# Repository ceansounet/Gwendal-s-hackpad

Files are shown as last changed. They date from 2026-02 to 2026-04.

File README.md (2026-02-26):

# Gwendal-s-hackpad
My personnal Hackpad

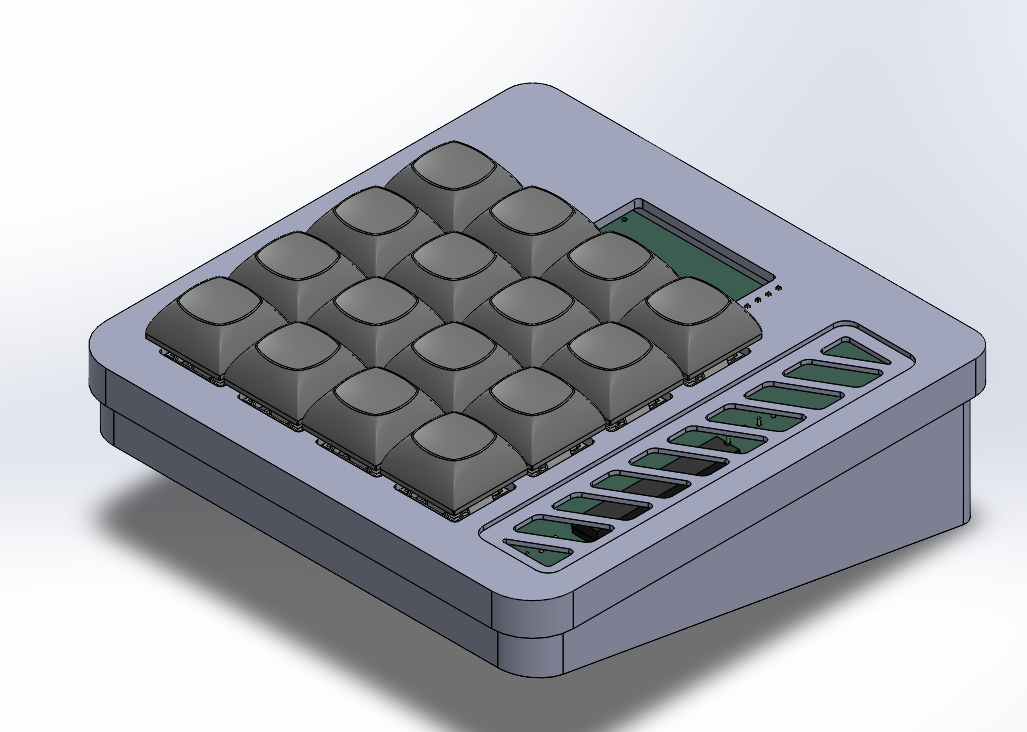
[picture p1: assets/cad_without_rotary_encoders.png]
cad


## PCB
here is the schematic of my pcb :

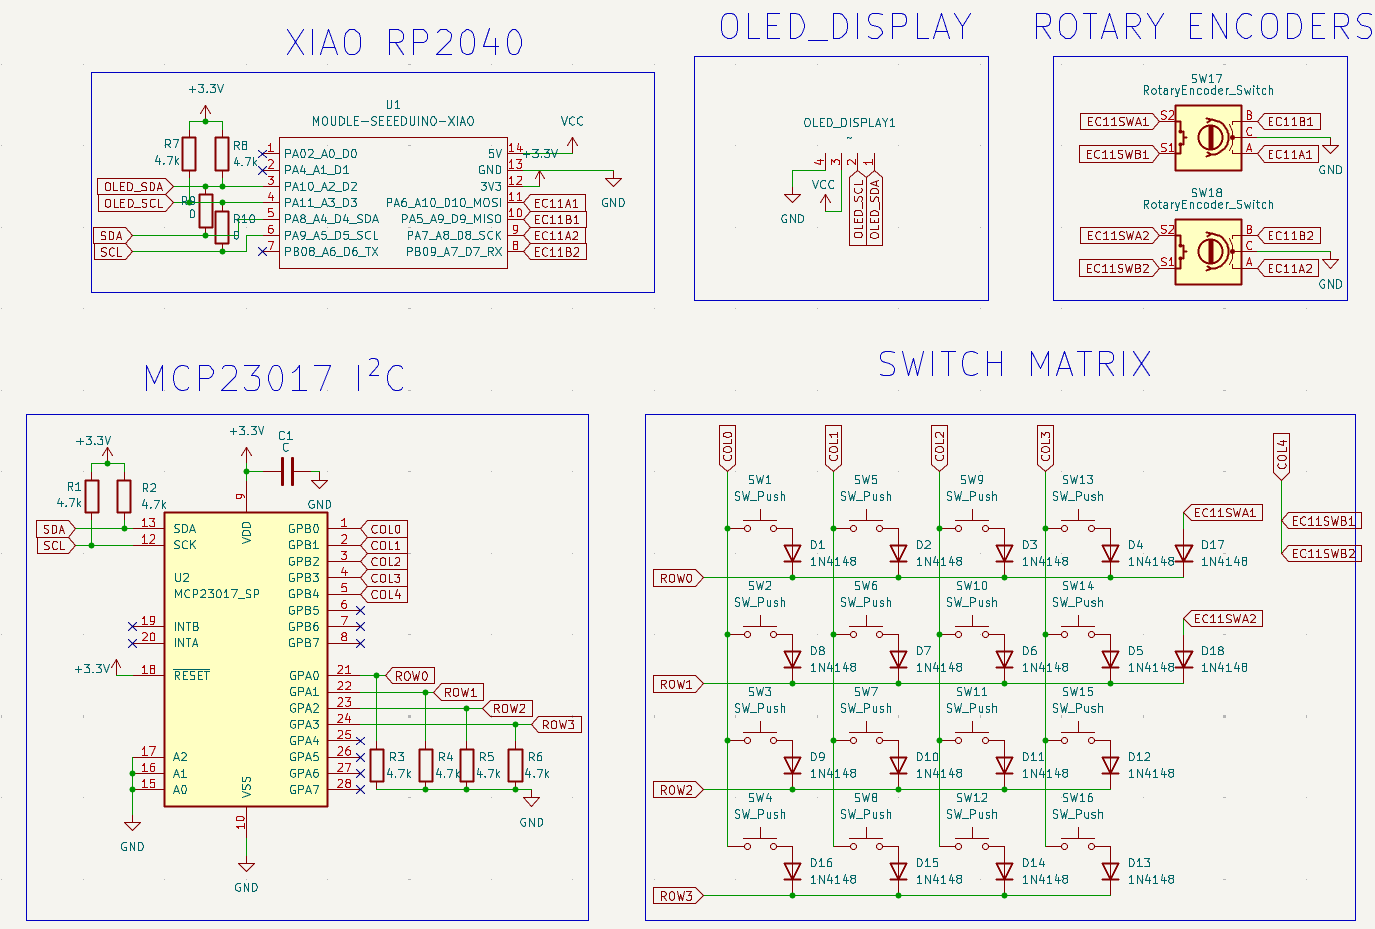
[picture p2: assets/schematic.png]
Schematic


and here is the resulting layout, it needs to be pretty compact to fit in the 100mm*100mm requirements

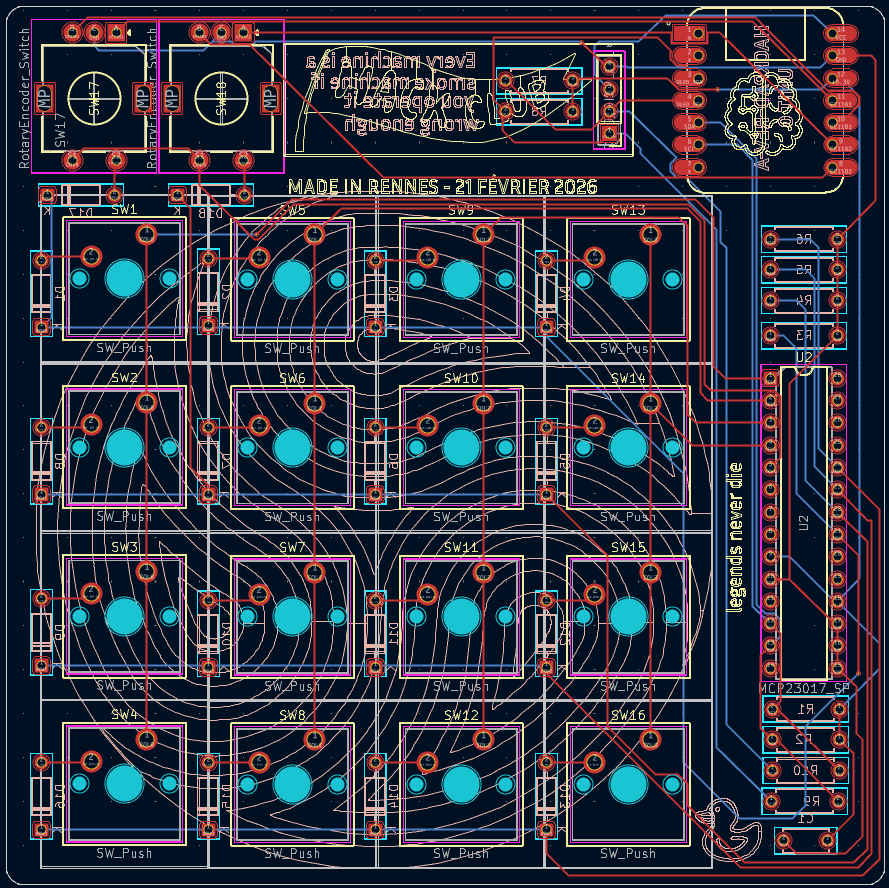
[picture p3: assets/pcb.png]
pcb


The silkscreen was made on figma and imported as an SVG. (sources are [here](pcb/assets))

## BONUS
Since I had extra space and the kit comes with them, I figured I could include the rotary encoders inside a bonus version of my hackpad, while the main version keeps only 16 inputs to fit within the limit

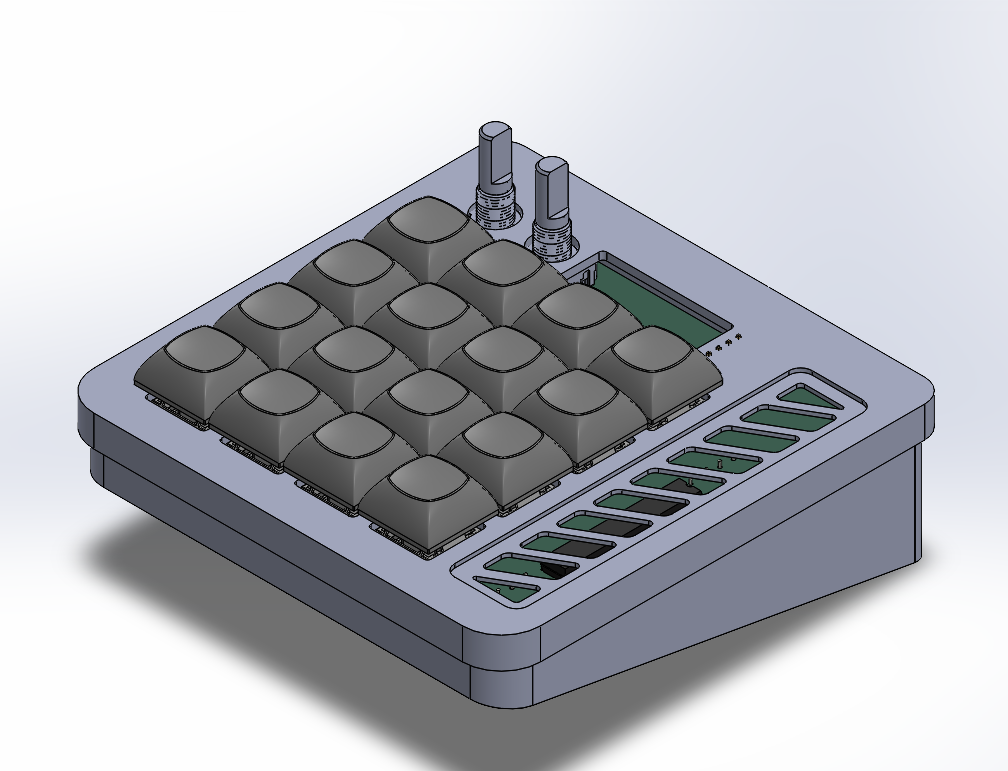
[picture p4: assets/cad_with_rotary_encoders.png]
cad bonus


## BOM:
Here should be everything you need to make this hackpad

in the kit :
- 16x Cherry MX Switches
- 16x DSA Keycaps
- 2x M3x5x4 Heatset inserts
- 2X M3x12mm SHCS Bolts
- 16x 1N4148 DO-35 Diodes
- 1x 0.91" 128x32 OLED Display
- 1x XIAO RP2040
- 1x Case (3 printed parts)

to source yourself :
- 1x MCP23017 (I²C IO expander)
- 1x 100nF Capacitor (decoupling the MCP power)
- 8x 4.7k ohm resistors (pull up/pull down resistors for the matrix and the I²C circuit)

Optional :
- 2x EC11 Rotary Encoder
- 2x 1N4148 DO-35 Diodes
- 1x 8cm² cork sheet (for the bottom of the case)

## EXTRA STUFF :
I designed this project in 4 days of vacation, learnt to use kicad and pcb design in general
If firmware doesn't support 2 different I²C circuits, I added 0 ohm resistors (R9 and R10), that can be soldered shut to make a single I²C circuit, currently it uses 2 by default for speed and stability.
I designed the case to be 3d printable without supports (exept the cutout bit on the top cover, purely for aesthetic purposes, feel free to fill it in to avoid supports entirely).
I made some firmware that should support the matrix, but does not support the encoders nor the OLED screen yet, I am waiting until I have actually made the board to test it.

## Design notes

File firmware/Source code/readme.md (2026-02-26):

# gwendals_hackpad

gwendals_hackpad

*A short description of the keyboard/project*

* Keyboard Maintainer: [gwendal](https://github.com/ceansounet)
* Hardware Supported: RP2040
* Hardware Availability: IDK

Make example for this keyboard (after setting up your build environment):

    make gwendals_hackpad:default

Flashing example for this keyboard:

    make gwendals_hackpad:default:flash

See the [build environment setup](https://docs.qmk.fm/#/getting_started_build_tools) and the [make instructions](https://docs.qmk.fm/#/getting_started_make_guide) for more information. Brand new to QMK? Start with our [Complete Newbs Guide](https://docs.qmk.fm/#/newbs).

## Bootloader

Enter the bootloader in 3 ways:

* **Bootmagic reset**: Hold down the key at (0,0) in the matrix (usually the top left key or Escape) and plug in the keyboard
* **Physical reset button**: Briefly press the button on the back of the PCB - some may have pads you must short instead
* **Keycode in layout**: Press the key mapped to `QK_BOOT` if it is available

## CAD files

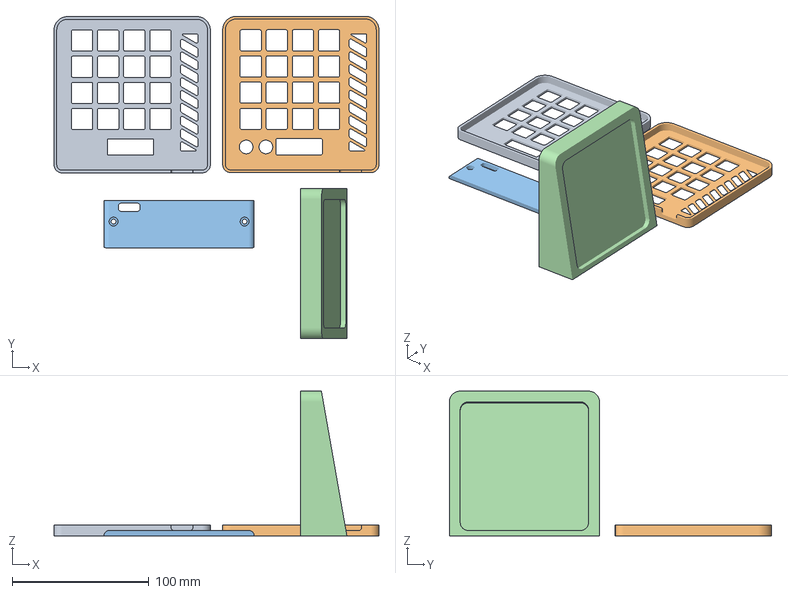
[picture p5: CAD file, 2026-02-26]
cad/3d print file.3mf
238.0 x 236.1 x 106.0 mm
Top_Cover_without_rotary_encoders.STEP
Top_Cover_with_rotary_encoders.STEP
Backplate.STEP
Bottom_part.STEP

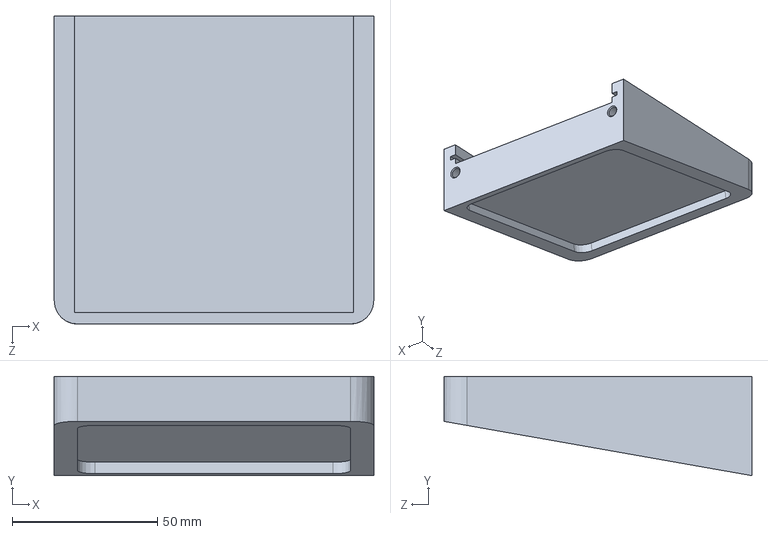
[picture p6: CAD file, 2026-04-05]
cad/Source cad/Bottom_part.SLDPRT
110.0 x 34.2 x 106.0 mm

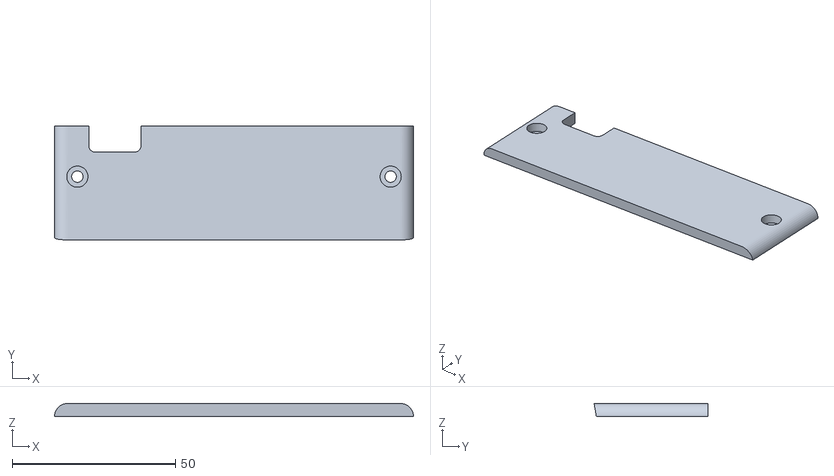
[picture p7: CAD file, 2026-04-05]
production/Backplate.stl
110.0 x 34.9 x 4.00

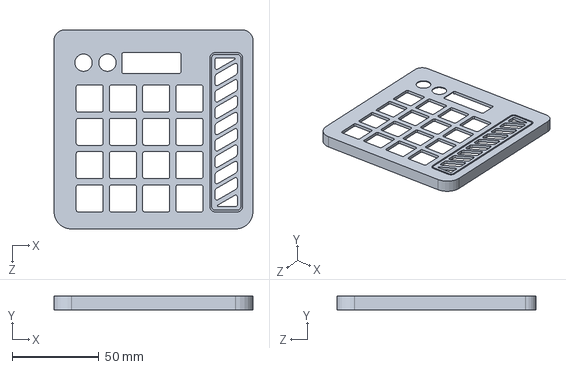
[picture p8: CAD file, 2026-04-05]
cad/Source cad/Top_Cover_with_rotary_encoders.SLDPRT
114.5 x 8.00 x 114.5 mm

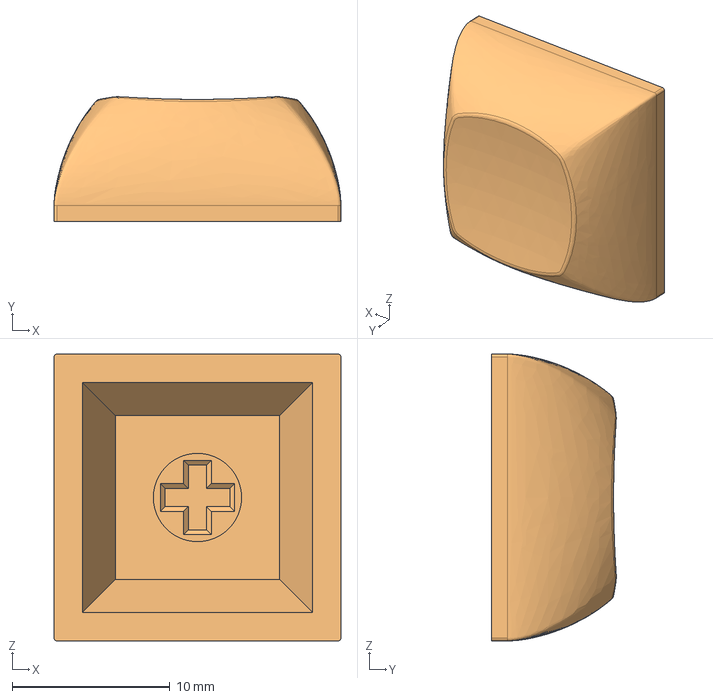
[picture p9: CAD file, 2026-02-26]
cad/Source cad/DSA 1u.step
18.2 x 7.91 x 18.2 mm

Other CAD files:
production/Bottom_part.stl
cad/Source cad/Backplate.SLDPRT
production/Top_Cover.STEP
cad/Source cad/Top_Cover_without_rotary_encoders.SLDPRT
production/Top_cover_BONUS_(with_rotary_encoders).stl

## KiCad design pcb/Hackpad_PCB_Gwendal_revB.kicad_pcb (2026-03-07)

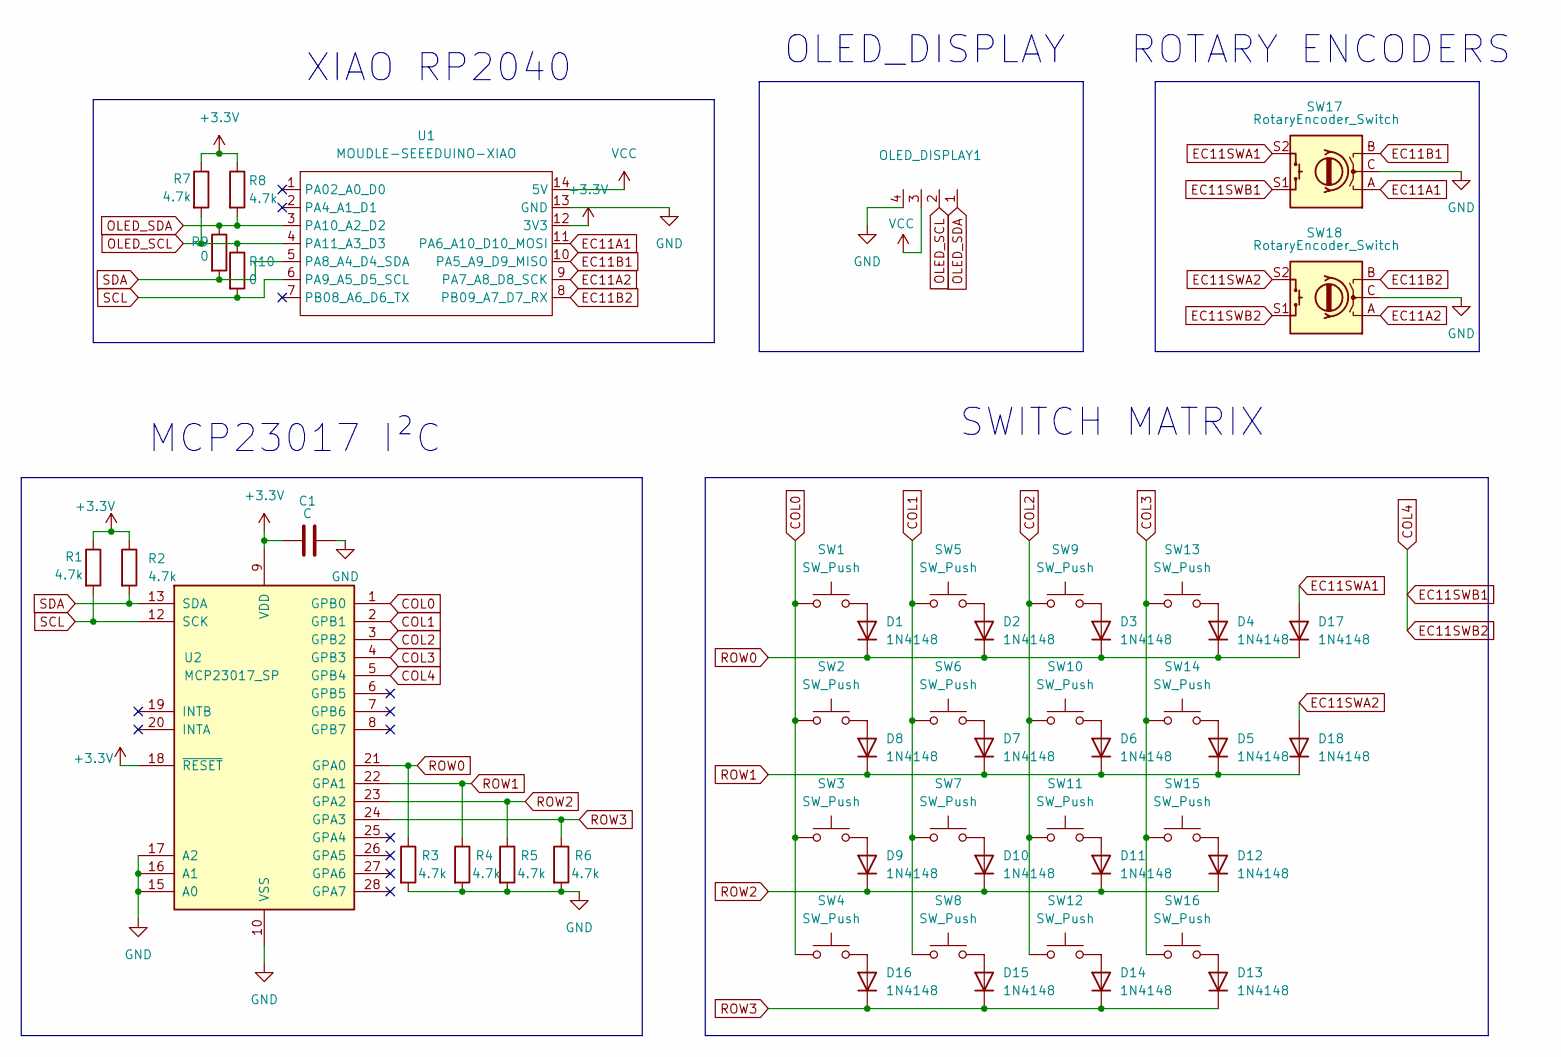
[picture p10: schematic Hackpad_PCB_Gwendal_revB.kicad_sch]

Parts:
C1: C; C_Disc_D5.0mm_W2.5mm_P5.00mm
D1, D2, D3, D4, D5, D6, D7, D8, D9, D10, D11, D12, D13, D14, D15, D16, D17, D18: 1N4148; D_DO-35_SOD27_P7.62mm_Horizontal
OLED_DISPLAY1: PinHeader_1x04_P2.54mm_Vertical
R1, R2, R3, R4, R5, R6, R7, R8: 4.7k; R_Axial_DIN0207_L6.3mm_D2.5mm_P7.62mm_Horizontal
R9, R10: 0; R_Axial_DIN0207_L6.3mm_D2.5mm_P7.62mm_Horizontal
SW1, SW2, SW3, SW4, SW5, SW6, SW7, SW8, SW9, SW10, SW11, SW12, SW13, SW14, SW15, SW16: SW_Push; SW_Cherry_MX_1.00u_PCB
SW17, SW18: RotaryEncoder_Switch; RotaryEncoder_Alps_EC11E-Switch_Vertical_H20mm
U1: MOUDLE-SEEEDUINO-XIAO; XIAO-Generic-Hybrid-14P-2.54-21X17.8MM
U2: MCP23017_SP; DIP-28_W7.62mm

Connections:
+3.3V: C1.1, R1.1, R2.1, R7.1, R8.1, U1.12 (3V3), U2.9 (VDD), U2.18 (~RESET)
COL0: SW1.1, SW2.1, SW3.1, SW4.1, U2.1 (GPB0)
COL1: SW5.1, SW6.1, SW7.1, SW8.1, U2.2 (GPB1)
COL2: SW9.1, SW10.1, SW11.1, SW12.1, U2.3 (GPB2)
COL3: SW13.1, SW14.1, SW15.1, SW16.1, U2.4 (GPB3)
COL4: SW17.S1, SW18.S1, U2.5 (GPB4)
EC11A1: SW17.A, U1.11 (PA6_A10_D10_MOSI)
EC11A2: SW18.A, U1.9 (PA7_A8_D8_SCK)
EC11B1: SW17.B, U1.10 (PA5_A9_D9_MISO)
EC11B2: SW18.B, U1.8 (PB09_A7_D7_RX)
EC11SWA1: D17.2 (A), SW17.S2
EC11SWA2: D18.2 (A), SW18.S2
GND: C1.2, OLED_DISPLAY1.4, R3.2, R4.2, R5.2, R6.2, SW17.C, SW18.C, U1.13 (GND), U2.10 (VSS), U2.15 (A0), U2.16 (A1), U2.17 (A2)
unnamed: D1.2 (A), SW1.2
unnamed: D2.2 (A), SW5.2
unnamed: D3.2 (A), SW9.2
unnamed: D4.2 (A), SW13.2
unnamed: D5.2 (A), SW14.2
unnamed: D6.2 (A), SW10.2
unnamed: D7.2 (A), SW6.2
unnamed: D8.2 (A), SW2.2
unnamed: D9.2 (A), SW3.2
unnamed: D10.2 (A), SW7.2
unnamed: D11.2 (A), SW11.2
unnamed: D12.2 (A), SW15.2
unnamed: D13.2 (A), SW16.2
unnamed: D14.2 (A), SW12.2
unnamed: D15.2 (A), SW8.2
unnamed: D16.2 (A), SW4.2
OLED_SCL: OLED_DISPLAY1.2, R7.2, R10.1, U1.4 (PA11_A3_D3)
OLED_SDA: OLED_DISPLAY1.1, R8.2, R9.1, U1.3 (PA10_A2_D2)
ROW0: D1.1 (K), D2.1 (K), D3.1 (K), D4.1 (K), D17.1 (K), R3.1, U2.21 (GPA0)
ROW1: D5.1 (K), D6.1 (K), D7.1 (K), D8.1 (K), D18.1 (K), R4.1, U2.22 (GPA1)
ROW2: D9.1 (K), D10.1 (K), D11.1 (K), D12.1 (K), R5.1, U2.23 (GPA2)
ROW3: D13.1 (K), D14.1 (K), D15.1 (K), D16.1 (K), R6.1, U2.24 (GPA3)
SCL: R1.2, R10.2, U1.6 (PA9_A5_D5_SCL), U2.12 (SCK)
SDA: R2.2, R9.2, U1.5 (PA8_A4_D4_SDA), U2.13 (SDA)
VCC: OLED_DISPLAY1.3, U1.14 (5V)

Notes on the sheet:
XIAO RP2040
MCP23017 I²C
ROTARY ENCODERS
OLED_DISPLAY
SWITCH MATRIX

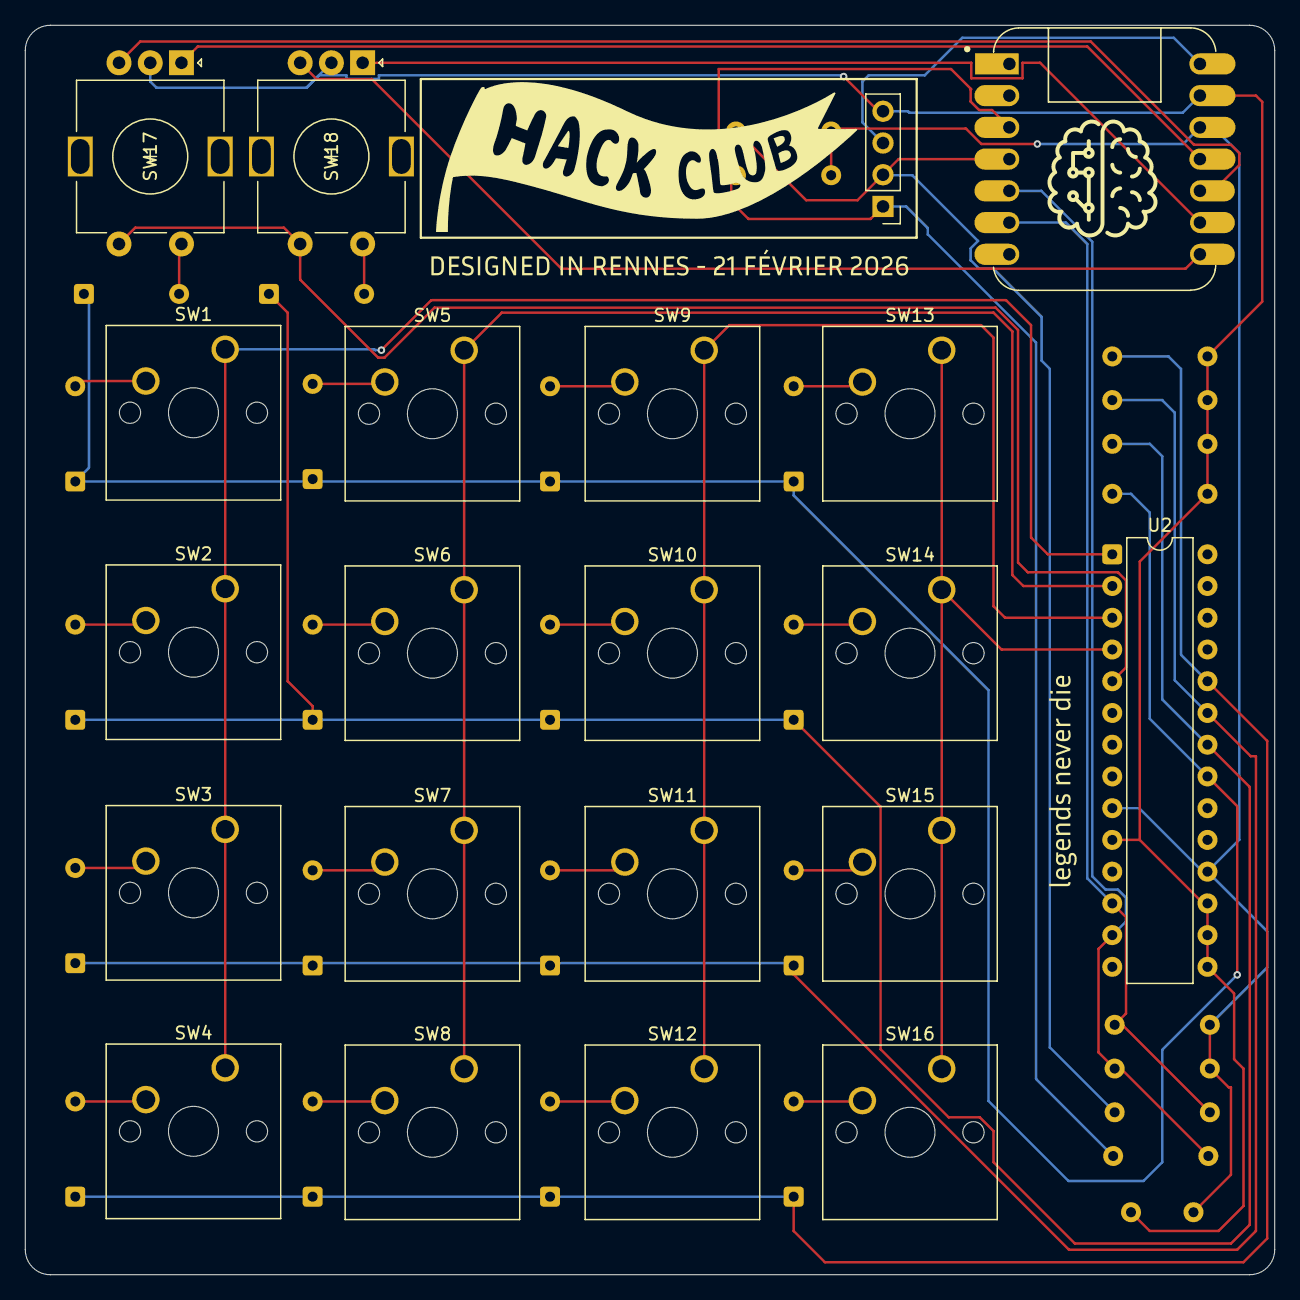
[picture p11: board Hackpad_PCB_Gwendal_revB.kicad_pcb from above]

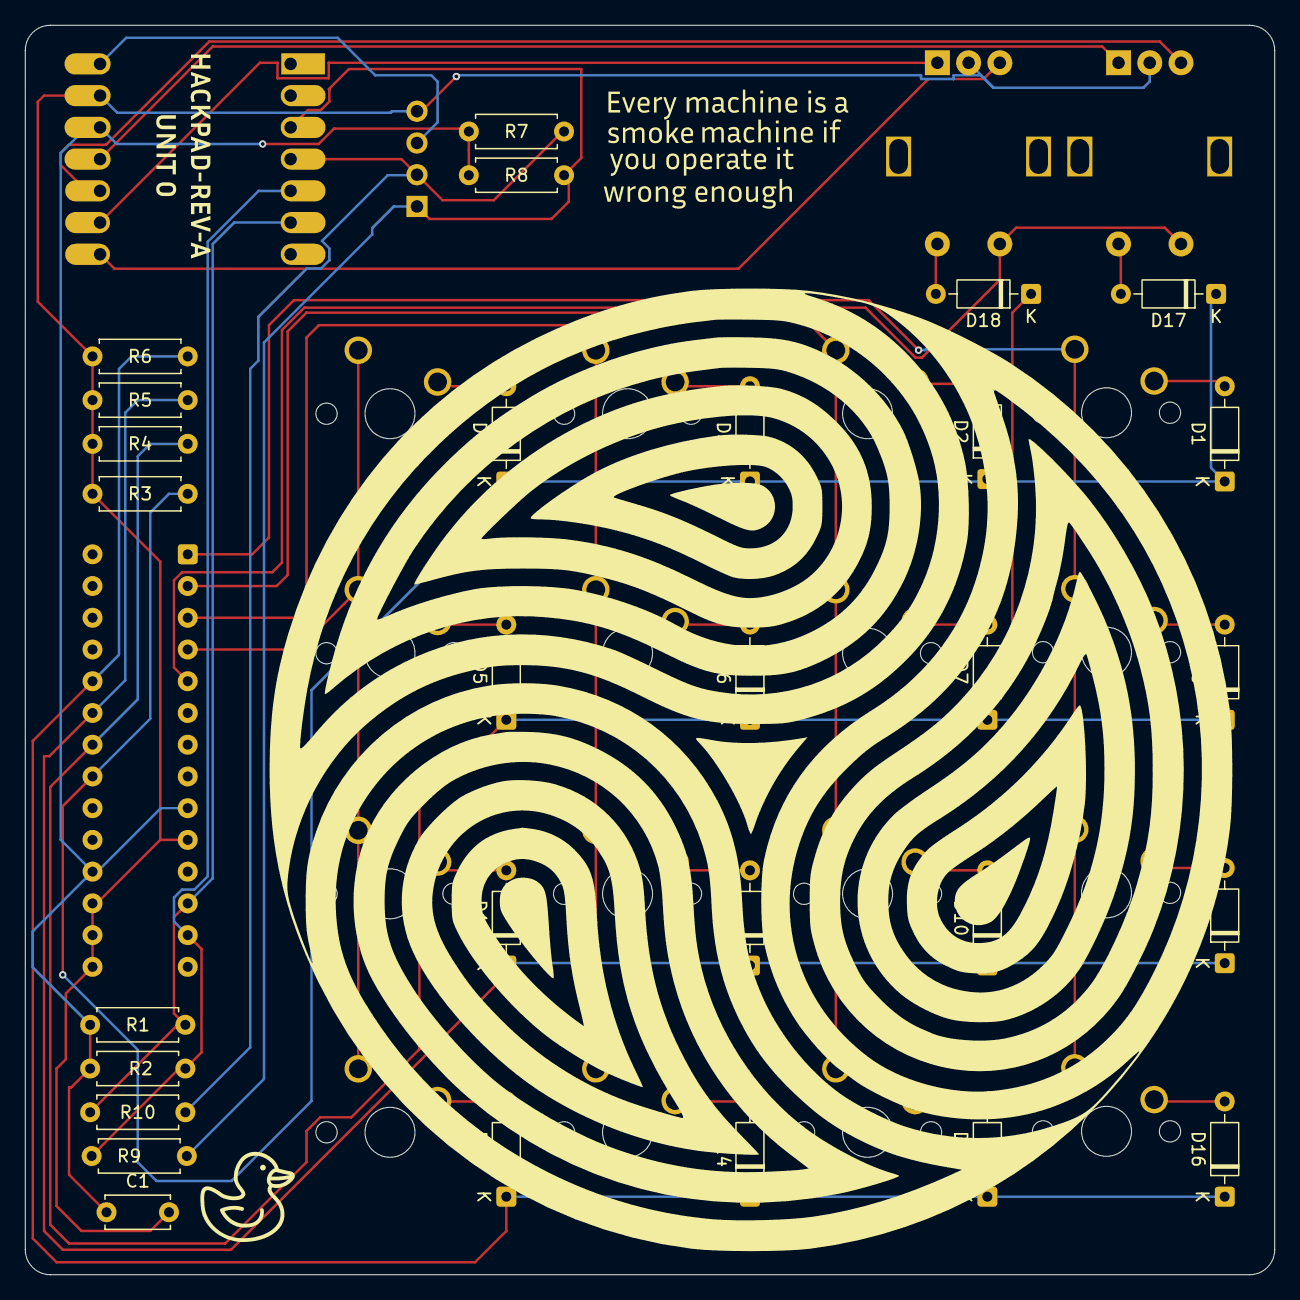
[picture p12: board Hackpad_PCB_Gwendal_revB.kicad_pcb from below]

Board: 2 copper layers, 100.0 x 100.0 mm, 50 parts (29 on the bottom side), 38 nets.

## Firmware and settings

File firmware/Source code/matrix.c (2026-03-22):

#include "quantum.h"
#include "i2c_master.h"

#define MCP23017_ADDR 0x40

#define IODIRA 0x00
#define IODIRB 0x01
#define GPPUA  0x0C
#define GPPUB  0x0D
#define GPIOA  0x12
#define GPIOB  0x13

void matrix_init_custom(void) {
    i2c_init();
    debug_enable = true;

    uint8_t data;

    // GPA = rows = outputs
    data = 0x00;
    i2c_write_register(MCP23017_ADDR, IODIRA, &data, 1, 100);

    // GPB = columns = inputs
    data = 0xFF;
    i2c_write_register(MCP23017_ADDR, IODIRB, &data, 1, 100);

    // No pull-ups on row outputs
    data = 0x00;
    i2c_write_register(MCP23017_ADDR, GPPUA, &data, 1, 100);

    // Pull-ups on columns
    data = 0xFF;
    i2c_write_register(MCP23017_ADDR, GPPUB, &data, 1, 100);

    // Idle state: all rows high
    data = 0xFF;
    i2c_write_register(MCP23017_ADDR, GPIOA, &data, 1, 100);
}

bool matrix_scan_custom(matrix_row_t current_matrix[]) {
    bool changed = false;
    uint8_t cols = 0;

    for (int r = 0; r < MATRIX_ROWS; r++) {
        // all rows high
        uint8_t all_high = 0xFF;
        i2c_write_register(MCP23017_ADDR, GPIOA, &all_high, 1, 100);

        wait_us(50);

        // drive one row low
        uint8_t row_state = (uint8_t)(0xFF & ~(1 << r));
        i2c_write_register(MCP23017_ADDR, GPIOA, &row_state, 1, 100);

        wait_us(200);

        if (i2c_read_register(MCP23017_ADDR, GPIOB, &cols, 1, 100) != I2C_STATUS_SUCCESS) {
            continue;
        }

        matrix_row_t new_state = (matrix_row_t)((~cols) & 0x1F);

        if (current_matrix[r] != new_state) {
            current_matrix[r] = new_state;
            changed = true;
        }
    }

    // restore idle state
    uint8_t all_high = 0xFF;
    i2c_write_register(MCP23017_ADDR, GPIOA, &all_high, 1, 100);

    return changed;
}

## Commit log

2026-02-23 SEEEENNNDDD IIITTTTTT
    [Backplate.stl, Bottom_part.stl, Hackpad_PCB_Gwendal_revB.kicad_pcb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]
2026-02-25 Edited Oled pullups to be 3.3v reference instead of 5v, I won't edit all of the pictures for such a small change.
    [Hackpad_PCB_Gwendal_revB.kicad_pcb, Hackpad_PCB_Gwendal_revB.kicad_sch]
2026-02-25 Updated the pictures to show to switch from logic level 5v to 3.3v on the I2C circuit for the oled screen.
2026-02-26 Added cad and code source files.
    [3d print file.3mf, Backplate.SLDPRT, Bottom_part.SLDPRT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]
2026-03-01 Added a copper fill zone to the front and back of the PCB.
    [Hackpad_PCB_Gwendal_revB.kicad_pcb]
2026-03-07 Updated "MADE IN RENNES" to "DESIGNED IN RENNES" on the pcb graphics, as JLCPCB failed the first audit because of it.
    [Hackpad_PCB_Gwendal_revB.kicad_pcb]
2026-03-22 Updated firmware, now every key works, still missing the OLED screen and the rotary encoder support
    [matrix.c]
2026-04-05 -added some material so that the top cover would print without supports -added chamfers to the heat set insert holes, and made them deeper -added a flexible tab at the back of the top cover to make i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
    [Backplate.SLDPRT, Backplate.stl, Bottom_part.SLDPRT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]
